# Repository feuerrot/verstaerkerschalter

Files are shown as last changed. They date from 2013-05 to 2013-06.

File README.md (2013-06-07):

# Verstärkerschalter

Dieses Projekt dient dazu, auf der Basis von
[vusb](http://www.obdev.at/vusb/) und
[powerswitch](http://www.obdev.at/products/vusb/powerswitch.html) die
Verstärker im [chaosdorf](https://www.chaosdorf.de) zu schalten.

Zudem hat die Platine bereits Bauteile für einen Anschluss per CAN-Bus, was
es später ermöglichen soll, die Platine an das geplante Bussystem im
Chaosdorf anzuschließen.

## Layout und so

### Schaltplan
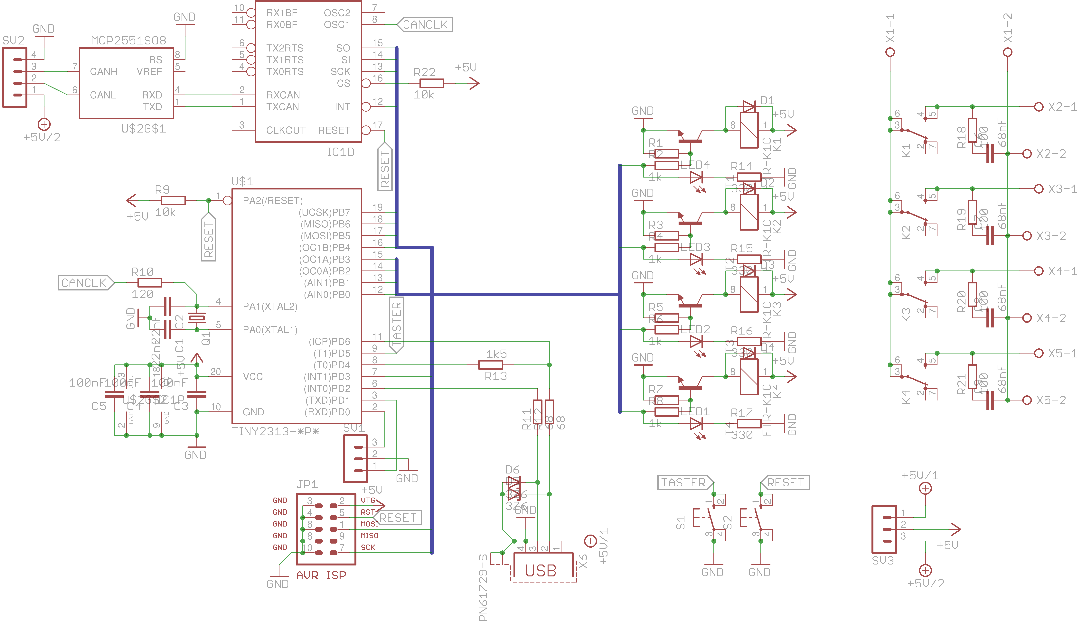
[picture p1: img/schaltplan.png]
Schaltplan der Verstärkerschaltung


### Layout
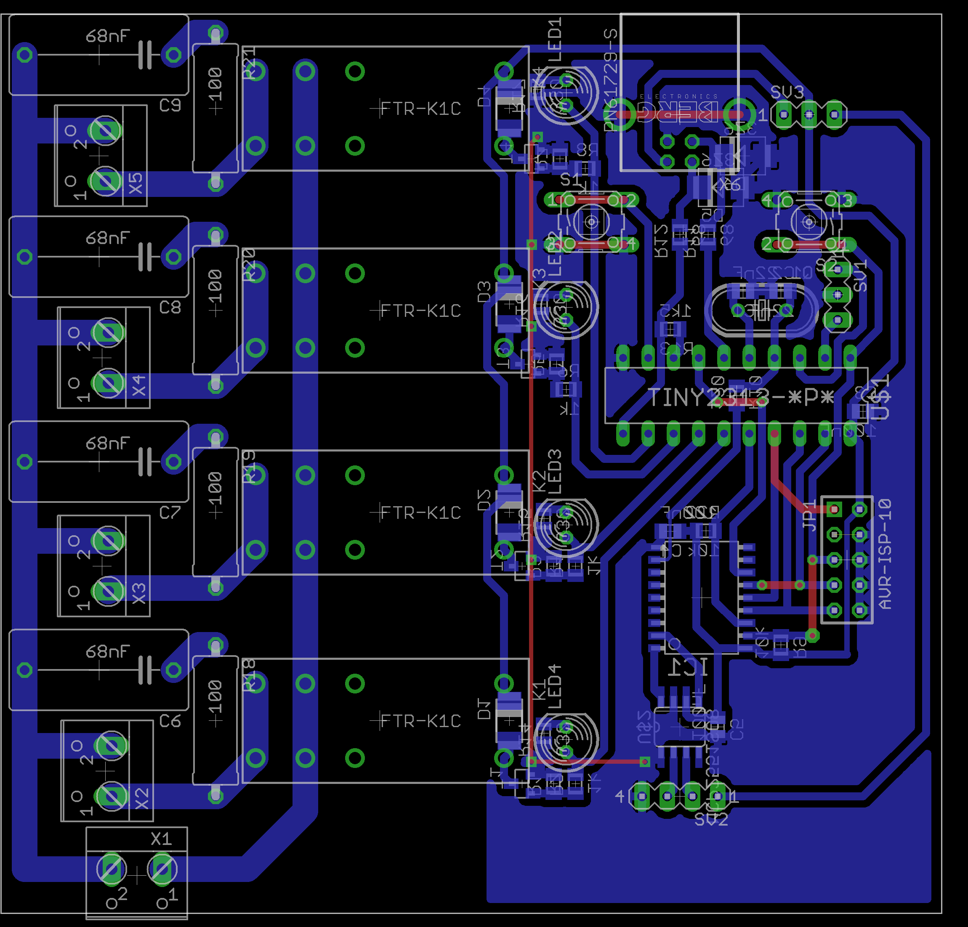
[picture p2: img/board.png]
Layout der Verstärkerschaltung


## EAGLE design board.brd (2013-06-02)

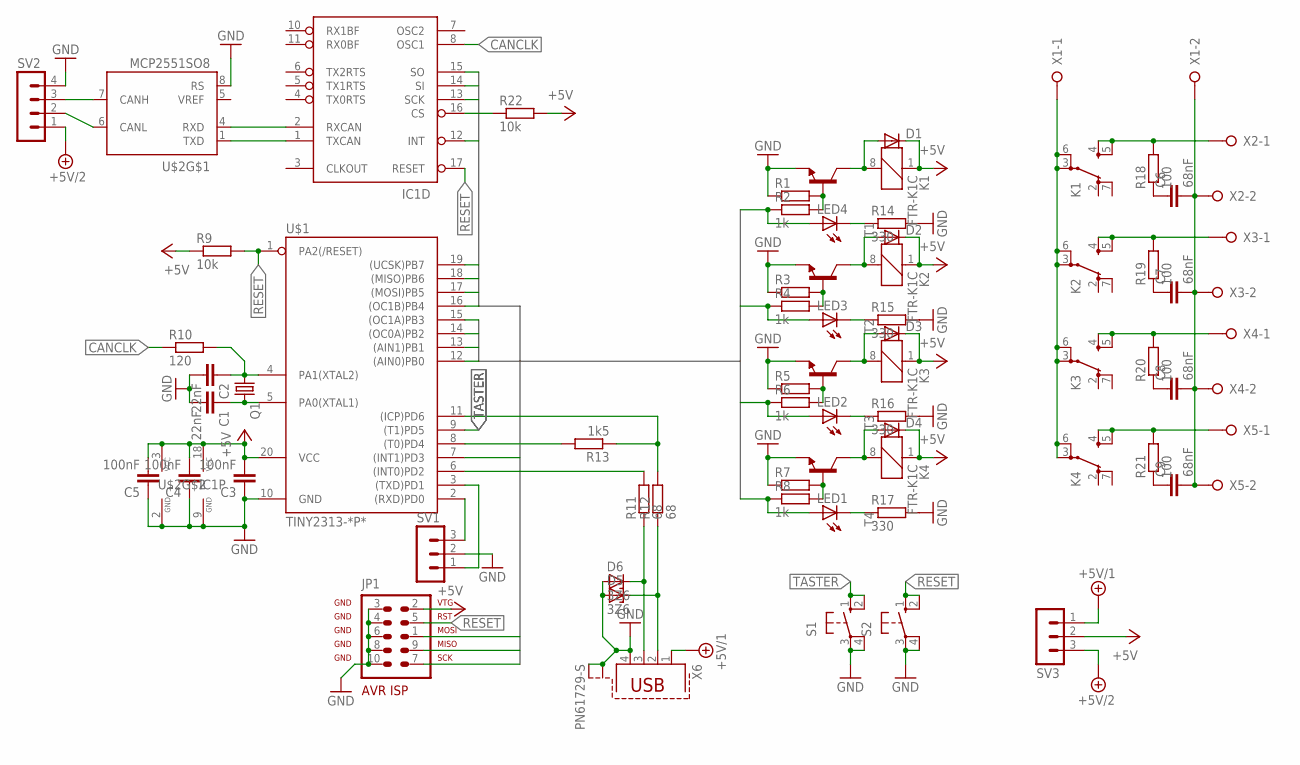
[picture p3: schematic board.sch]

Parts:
C1, C2: 22nF; C0805
C3, C4, C5: 100nF; C0805
C6, C7, C8, C9: 68nF; C150-084X183
D1, D2, D3, D4: DIODE-DO-214AC; DO-214AC
D5, D6: 3Z6; SMB
IC1: MCP2515SO; SO-18W
JP1: AVR-ISP-10
K1, K2, K3, K4: FTR-K1C
LED1, LED2, LED3, LED4: LED5MM
Q1: CRYSTALHC49U70; HC49U70
R1, R3, R5, R7: R-EU_M0805; M0805
R2, R4, R6, R8: 1k; M0805
R9, R22: 10k; M0805
R10: 120; M0805
R11, R12: 68; M0805
R13: 1k5; M0805
R14, R15, R16, R17: 330; M0805
R18, R19, R20, R21: 100; P0613/15
S1, S2: 10-XX; B3F-10XX
SV1, SV3: MA03-1
SV2: MA04-1
T1, T2, T3, T4: -NPN-SOT23-EBC; SOT23-EBC
U$1: TINY2313-*P*; DIL20
U$2: MCP2551SO8; SO08
X1, X2, X3, X4, X5: W237-02P; W237-132
X6: PN61729-S

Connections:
+5V: C3.2, C4.2, C5.2, D1.C, D2.C, D3.C, D4.C, IC1.18 (VCC), JP1.2, K1.1, K2.1, K3.1, K4.1, R9.1, R22.2, SV3.2, U$1.20 (VCC), U$2.3 (VCC)
+5V/1: SV3.1, X6.1
+5V/2: SV2.1, SV3.3
CANCLK: IC1.8 (OSC1), R10.1
CS: IC1.16 (CS), R22.1, U$1.16 ((OC1B)PB4)
GND: C1.2, C2.2, C3.1, C4.1, C5.1, D5.A, D6.A, IC1.9 (GND), JP1.3, JP1.4, JP1.6, JP1.8, JP1.10, R1.1, R3.1, R5.1, R7.1, R14.2, R15.2, R16.2, R17.2, S1.3, S1.4 (P1), S2.3, S2.4 (P1), SV1.2, SV2.4, T1.E, T2.E, T3.E, T4.E, U$1.10 (GND), U$2.2 (GND), U$2.8 (RS), X6.4, X6.S1, X6.S2
INT: IC1.12 (INT), U$1.7 ((INT1)PD3)
MISO: IC1.15 (SO), JP1.9, U$1.18 ((MISO)PB6)
MOSI: IC1.14 (SI), JP1.1, U$1.17 ((MOSI)PB5)
unnamed: K1.3 (PA), K1.6 (PB), K2.3 (PA), K2.6 (PB), K3.3 (PA), K3.6 (PB), K4.3 (PA), K4.6 (PB), X1.1
unnamed: C6.2, C7.2, C8.2, C9.2, X1.2, X2.2, X3.2, X4.2, X5.2
unnamed: K1.4 (SA), K1.5 (SB), R18.2, X2.1
unnamed: K2.4 (SA), K2.5 (SB), R19.2, X3.1
unnamed: K3.4 (SA), K3.5 (SB), R20.2, X4.1
unnamed: K4.4 (SA), K4.5 (SB), R21.2, X5.1
unnamed: D1.A, K1.8 (2), T1.C
unnamed: D2.A, K2.8 (2), T2.C
unnamed: R1.2, R2.2, T1.B
unnamed: D3.A, K3.8 (2), T3.C
unnamed: R5.2, R6.2, T3.B
unnamed: D4.A, K4.8 (2), T4.C
unnamed: R7.2, R8.2, T4.B
unnamed: C2.1, Q1.1, R10.2, U$1.4 (PA1(XTAL2))
unnamed: C1.1, Q1.2, U$1.5 (PA0(XTAL1))
unnamed: IC1.2 (RXCAN), U$2.4 (RXD)
unnamed: IC1.1 (TXCAN), U$2.1 (TXD)
unnamed: LED4.K (C), R14.1
unnamed: R11.2, U$1.6 ((INT0)PD2)
unnamed: D6.C, R11.1, X6.3
unnamed: D5.C, R12.1, X6.2
unnamed: LED3.K (C), R15.1
unnamed: R12.2, R13.1, U$1.11 ((ICP)PD6)
unnamed: SV1.1, U$1.3 ((TXD)PD1)
unnamed: SV1.3, U$1.2 ((RXD)PD0)
unnamed: LED2.K (C), R16.1
unnamed: LED1.K (C), R17.1
unnamed: R13.2, U$1.8 ((T0)PD4)
unnamed: C6.1, R18.1
unnamed: C9.1, R21.1
unnamed: C8.1, R20.1
unnamed: C7.1, R19.1
unnamed: SV2.3, U$2.7 (CANH)
unnamed: SV2.2, U$2.6 (CANL)
unnamed: R3.2, R4.2, T2.B
RELAI0: LED1.A, R8.1, U$1.12 ((AIN0)PB0)
RELAI1: LED2.A, R6.1, U$1.13 ((AIN1)PB1)
RELAI2: LED3.A, R4.1, U$1.14 ((OC0A)PB2)
RELAI3: LED4.A, R2.1, U$1.15 ((OC1A)PB3)
RESET: IC1.17 (RESET), JP1.5, R9.2, S2.1 (S), S2.2 (S1), U$1.1 (PA2(/RESET))
SCK: IC1.13 (SCK), JP1.7, U$1.19 ((UCSK)PB7)
TASTER: S1.1 (S), S1.2 (S1), U$1.9 ((T1)PD5)

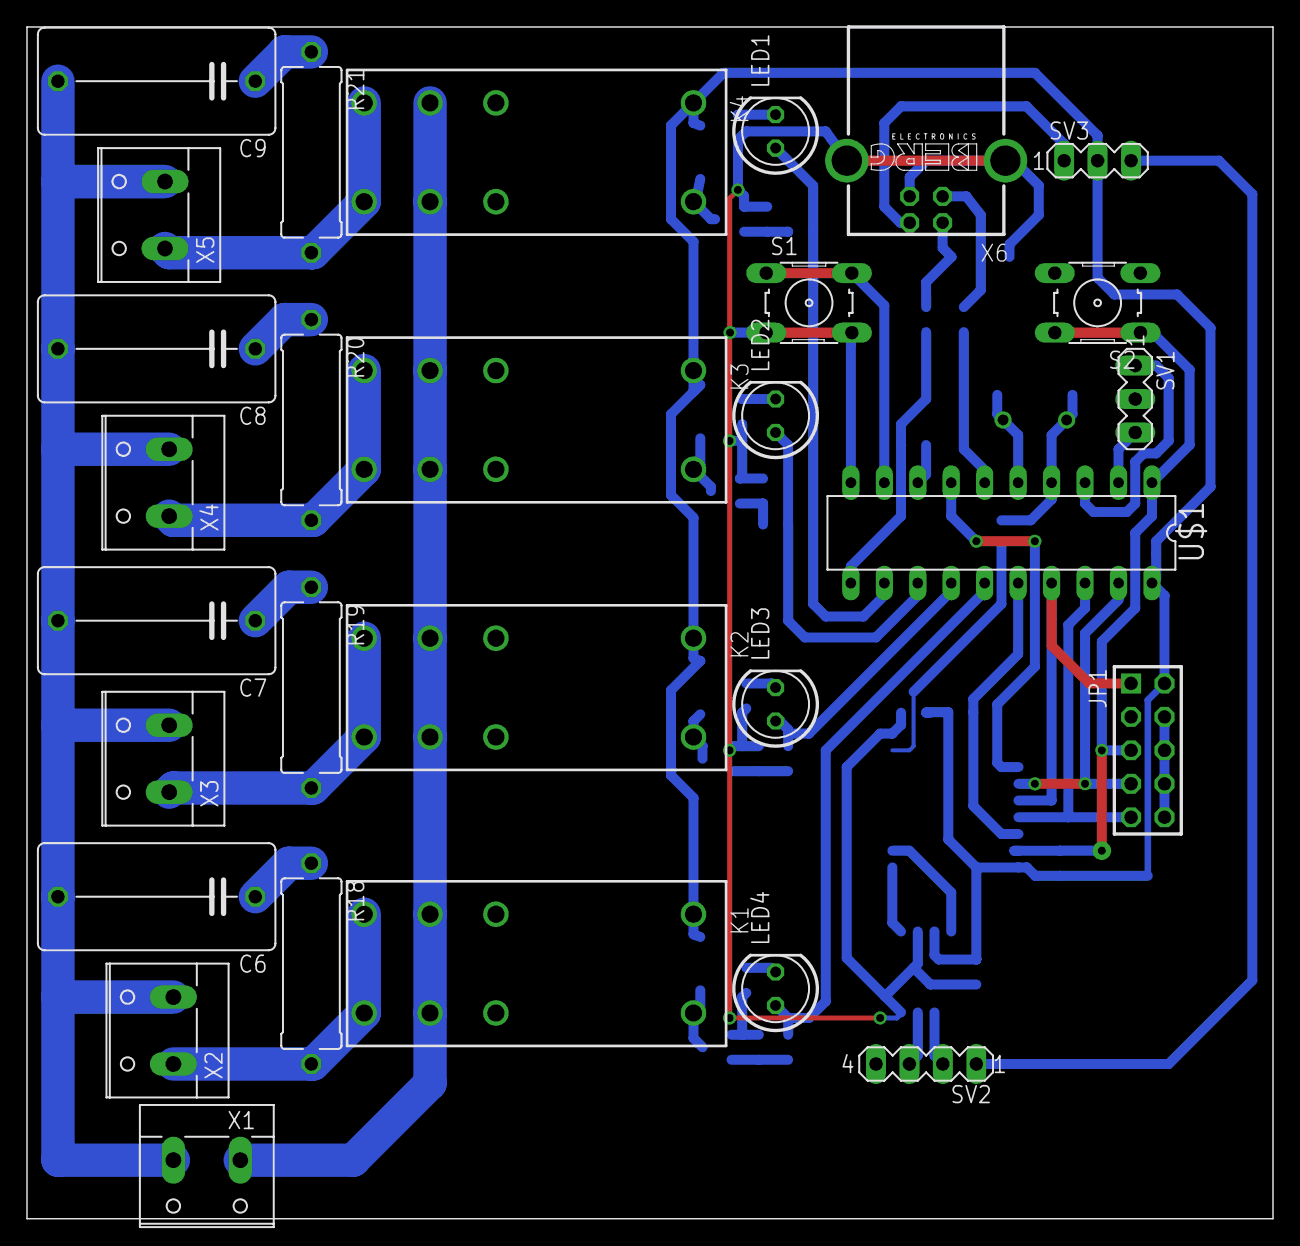
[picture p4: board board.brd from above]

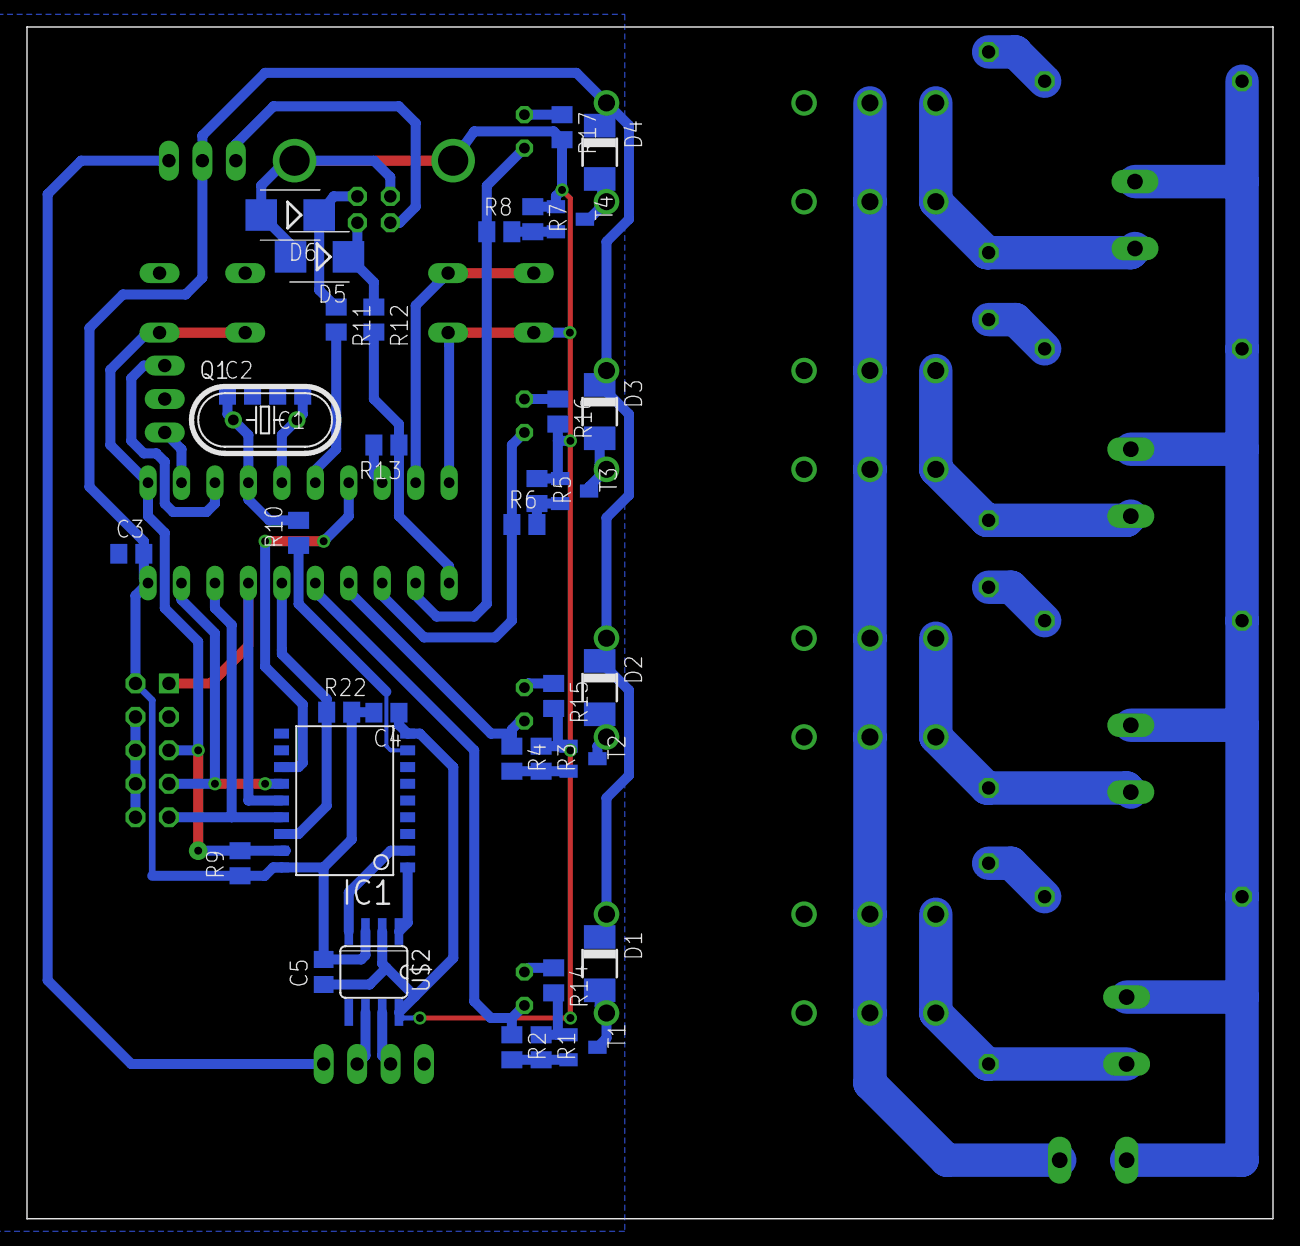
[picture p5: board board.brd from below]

Board: 2 copper layers, 94.6 x 90.5 mm, 65 parts (36 on the bottom side), 51 nets.

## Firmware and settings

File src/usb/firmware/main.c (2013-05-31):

/* Name: main.c
 * Project: PowerSwitch based on AVR USB driver
 * Author: Christian Starkjohann
 * Creation Date: 2005-01-16
 * Tabsize: 4
 * Copyright: (c) 2005 by OBJECTIVE DEVELOPMENT Software GmbH
 * License: GNU GPL v2 (see License.txt) or proprietary (CommercialLicense.txt)
 * This Revision: $Id$
 */

#include <avr/io.h>
#include <avr/interrupt.h>
#include <avr/pgmspace.h>
#include <avr/eeprom.h>
#include <avr/wdt.h>

#include "usbdrv.h"
#include <util/delay.h>

volatile uint8_t relaistatus;

static void outputByte(){
    PORTB = (PORTB & ~0x0f) | (relaistatus & 0x0f);
}



/* We poll for the timer interrupt instead of declaring an interrupt handler
 * with global interrupts enabled. This saves recursion depth. Our timer does
 * not need high precision and does not run at a high rate anyway.
 */

USB_PUBLIC uchar usbFunctionSetup(uchar data[8]){
usbRequest_t    *rq = (void *)data;
uchar           status = relaistatus;
static uchar    replyBuf[2];

    usbMsgPtr = replyBuf;
    if(rq->bRequest == 0){  /* ECHO */
        replyBuf[0] = rq->wValue.bytes[0];
        replyBuf[1] = rq->wValue.bytes[1];
        return 2;
    }
    if(rq->bRequest == 1){  /* GET_STATUS -> result = 2 bytes */
        replyBuf[0] = status;
        replyBuf[1] = 0;
        return 2;
    }
    if(rq->bRequest == 2 || rq->bRequest == 3){ /* SWITCH_ON or SWITCH_OFF, index = bit number */
        uchar bit = rq->wIndex.bytes[0] & 7;
        uchar mask = 1 << bit;
        uchar needChange, isOn = status & mask;
        if(rq->bRequest == 2){  /* SWITCH_ON */
            status |= mask;
            needChange = !isOn;
        }else{              /* SWITCH_OFF */
            status &= ~mask;
            needChange = isOn;
        }
        relaistatus =  status;
    }
    outputByte();
    return 0;
}

/* allow some inter-device compatibility */
#if !defined TCCR0 && defined TCCR0B
#define TCCR0   TCCR0B
#endif
#if !defined TIFR && defined TIFR0
#define TIFR    TIFR0
#endif

int main(void){

    wdt_enable(WDTO_2S);
    DDRB = ~(1<<PB6);
    PORTB = (1<<PB4);          /* no pullups on USB pins */
    DDRD = ~((1<<PD2) | (1<<PD3) | (1<<PD5));   /* all outputs except PD2 = INT0 */
    PORTD = (1<<PD5);
/* We fake an USB disconnect by pulling D+ and D- to 0 during reset. This is
 * necessary if we had a watchdog reset or brownout reset to notify the host
 * that it should re-enumerate the device. Otherwise the host's and device's
 * concept of the device-ID would be out of sync.
 */
    DDRD = ~USBMASK;    /* set all pins as outputs except USB */
    usbDeviceDisconnect();  /* enforce re-enumeration, do this while interrupts are disabled! */
    _delay_ms(550);
    usbDeviceConnect();
    TCCR0 = 5;          /* set prescaler to 1/1024 */
    usbInit();
    sei();
    for(;;){    /* main event loop */
        wdt_reset();
        usbPoll();
        if(TIFR & (1 << TOV0)){
            TIFR |= 1 << TOV0;  /* clear pending flag */
        }
    }
    return 0;
}

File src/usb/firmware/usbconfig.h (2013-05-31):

/* Name: usbconfig.h
 * Project: AVR USB driver
 * Author: Christian Starkjohann
 * Creation Date: 2005-04-01
 * Tabsize: 4
 * Copyright: (c) 2005 by OBJECTIVE DEVELOPMENT Software GmbH
 * License: GNU GPL v2 (see License.txt) or proprietary (CommercialLicense.txt)
 * This Revision: $Id: usbconfig.h 43 2005-04-10 21:04:36Z cs $
 */

#ifndef __usbconfig_h_included__
#define __usbconfig_h_included__

/*
General Description:
This file contains parts of the USB driver which can be configured and can or
must be adapted to your hardware.

Please note that the usbdrv contains a usbconfig-prototype.h file now. We
recommend that you use that file as a template because it will always list
the newest features and options.
*/

/* ---------------------------- Hardware Config ---------------------------- */

#define USB_CFG_CLOCK_KHZ       (F_CPU/1000)

#define USB_CFG_IOPORTNAME      D
/* This is the port where the USB bus is connected. When you configure it to
 * "B", the registers PORTB, PINB and DDRB will be used.
 */
#define USB_CFG_DMINUS_BIT      6
/* This is the bit number in USB_CFG_IOPORT where the USB D- line is connected.
 * This may be any bit in the port.
 */
#define USB_CFG_DPLUS_BIT       2
/* This is the bit number in USB_CFG_IOPORT where the USB D+ line is connected.
 * This may be any bit in the port. Please note that D+ must also be connected
 * to interrupt pin INT0!
 */
/* #define USB_CFG_CLOCK_KHZ       (F_CPU/1000) */
/* Clock rate of the AVR in MHz. Legal values are 12000, 16000 or 16500.
 * The 16.5 MHz version of the code requires no crystal, it tolerates +/- 1%
 * deviation from the nominal frequency. All other rates require a precision
 * of 2000 ppm and thus a crystal!
 * Default if not specified: 12 MHz
 */

/* ----------------------- Optional Hardware Config ------------------------ */

#define USB_CFG_PULLUP_IOPORTNAME   D 
/* If you connect the 1.5k pullup resistor from D- to a port pin instead of
 * V+, you can connect and disconnect the device from firmware by calling
 * the macros usbDeviceConnect() and usbDeviceDisconnect() (see usbdrv.h).
 * This constant defines the port on which the pullup resistor is connected.
 */
 #define USB_CFG_PULLUP_BIT          4 
/* This constant defines the bit number in USB_CFG_PULLUP_IOPORT (defined
 * above) where the 1.5k pullup resistor is connected. See description
 * above for details.
 */

/* --------------------------- Functional Range ---------------------------- */

#define USB_CFG_HAVE_INTRIN_ENDPOINT    0
/* Define this to 1 if you want to compile a version with two endpoints: The
 * default control endpoint 0 and an interrupt-in endpoint 1.
 */
#define USB_CFG_HAVE_INTRIN_ENDPOINT3   0
/* Define this to 1 if you want to compile a version with three endpoints: The
 * default control endpoint 0, an interrupt-in endpoint 1 and an interrupt-in
 * endpoint 3. You must also enable endpoint 1 above.
 */
#define USB_CFG_IMPLEMENT_HALT          0
/* Define this to 1 if you also want to implement the ENDPOINT_HALT feature
 * for endpoint 1 (interrupt endpoint). Although you may not need this feature,
 * it is required by the standard. We have made it a config option because it
 * bloats the code considerably.
 */
#define USB_CFG_INTR_POLL_INTERVAL      10
/* If you compile a version with endpoint 1 (interrupt-in), this is the poll
 * interval. The value is in milliseconds and must not be less than 10 ms for
 * low speed devices.
 */
#define USB_CFG_IS_SELF_POWERED         1
/* Define this to 1 if the device has its own power supply. Set it to 0 if the
 * device is powered from the USB bus.
 */
#define USB_CFG_MAX_BUS_POWER           400
/* Set this variable to the maximum USB bus power consumption of your device.
 * The value is in milliamperes. [It will be divided by two since USB
 * communicates power requirements in units of 2 mA.]
 */
#define USB_CFG_IMPLEMENT_FN_WRITE      0
/* Set this to 1 if you want usbFunctionWrite() to be called for control-out
 * transfers. Set it to 0 if you don't need it and want to save a couple of
 * bytes.
 */
#define USB_CFG_IMPLEMENT_FN_READ       0
/* Set this to 1 if you need to send control replies which are generated
 * "on the fly" when usbFunctionRead() is called. If you only want to send
 * data from a static buffer, set it to 0 and return the data from
 * usbFunctionSetup(). This saves a couple of bytes.
 */
#define USB_CFG_IMPLEMENT_FN_WRITEOUT   0
/* Define this to 1 if you want to use interrupt-out (or bulk out) endpoint 1.
 * You must implement the function usbFunctionWriteOut() which receives all
 * interrupt/bulk data sent to endpoint 1.
 */
#define USB_CFG_HAVE_FLOWCONTROL        0
/* Define this to 1 if you want flowcontrol over USB data. See the definition
 * of the macros usbDisableAllRequests() and usbEnableAllRequests() in
 * usbdrv.h.
 */
/* #define USB_RX_USER_HOOK(data, len)     if(usbRxToken == (uchar)USBPID_SETUP) blinkLED(); */
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

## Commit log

2013-05-23 adding circuit and board
2013-05-23 polygon auf dem board angepasst, schaltplan angepasst
    [board.brd, board.sch]
2013-05-31 Hinzufügen der Firmware für usb
    Die Firmware ist von [Objective Development](http://www.obdev.at/products/vusb/powerswitch.html) und steht unter der GPLv2
2013-05-31 fixing the link to the circuit
2013-05-31 Some subtle layout changes
    [board.brd]
2013-05-31 fixing the fixing
    [board.brd]
2013-05-31 moar fixing
    [board.brd]
2013-05-31 New image of the board
2013-06-01 Moving one resistor for USB and the ISP-header
    [board.brd]
2013-06-01 The image of the board has changed
2013-06-02 Adding choice of powersupply, enhancing supply of the tiny, board is a touch larger
    [board.brd, board.sch]

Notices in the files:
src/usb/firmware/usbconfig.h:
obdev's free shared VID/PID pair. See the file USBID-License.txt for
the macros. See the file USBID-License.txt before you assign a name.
